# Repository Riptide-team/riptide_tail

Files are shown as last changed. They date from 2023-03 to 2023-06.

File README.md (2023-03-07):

# Compilation

## Arduino makefile

To compile and upload the code on the Arduino, [Arduino-Makefile](https://github.com/sudar/Arduino-Makefile) is used. Once installed, go to src, check that the arduino port is the port put in the Makefile at `MONITOR_PORT  = /dev/ttyUSB0`, and execute `make upload` 

# Serial communication

## Baudrate

The baudrate is `115200` and the communication is operating over usb between arduino and Raspberry Pi.

## Commands from raspberry

### Command frame
Commands from raspberry are sent using bytes. The line is finished by a `LF` (`\n`).

### Frame content
Bytes are hex values between 1000 and 2000 (coded on two consecutive bytes) which are direct us request on the output channel.
Channel order is :

- Thruster channel
- D fin channel
- P fin channel
- S fin channel

### Example

All to neutral:

`\0x05\0xDC\0x05\0xDC\0x05\0xDC\0x05\0xDC\0x0A`

Thruster full forward, fins full backward:

`\0x07\0xD0\0x03\0xE8\0x03\0xE8\0x53\0xE8\0x0A`

## Commands from arduino

### Command frame
Commands from raspberry are sent using bytes. The line is finished by a `LF` (`\n`).

### Frame content
Bytes are hex values between 1000 and 2000 (on three hexadecimal digits) which are direct us request from the RC captured by arduino and real generated PWM to actuators.
Channel order is :

- Thruster channel
- D fin channel
- P fin channel
- S fin channel
- RC channel 1 (Manual button)
- RC channel 2 (Timer button)
- RC channel 3 (Thruster)
- RC channel 4 (D fin)
- RC channel 5 (P fin)
- RC channel 6 (S fin)

### Example

All to neutral:

`\0x05\0xDC\0x05\0xDC\0x05\0xDC\0x05\0xDC\0x05\0xDC\0x05\0xDC\0x05\0xDC\0x05\0xDC\0x05\0xDC\0x05\0xDC\0x0A`

Thruster full forward, fins full backward, in manual mode, with timer at the minimum, so the RC captured commands are commands applied to the actuators:

`\0x07\0xD0\0x03\0xE8\0x03\0xE8\0x53\0xE8\0x07\0xD0\0x03\0xE8\0x07\0xD0\0x03\0xE8\0x03\0xE8\0x53\0xE8\0x0A`

## Picocom serial debug

To debug the serial communication, picocom can be used with the following configuration to correctly print hex characters:

```bash
picocom --imap spchex,nrmhex,8bithex,lfcrlf /dev/ttyUSB0 -b 115200
```

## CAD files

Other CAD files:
cad/parts/riptide_servomotors_bracket.FCStd
cad/parts/riptide_tail_top.FCStd
cad/parts/riptide_tail_bottom.FCStd

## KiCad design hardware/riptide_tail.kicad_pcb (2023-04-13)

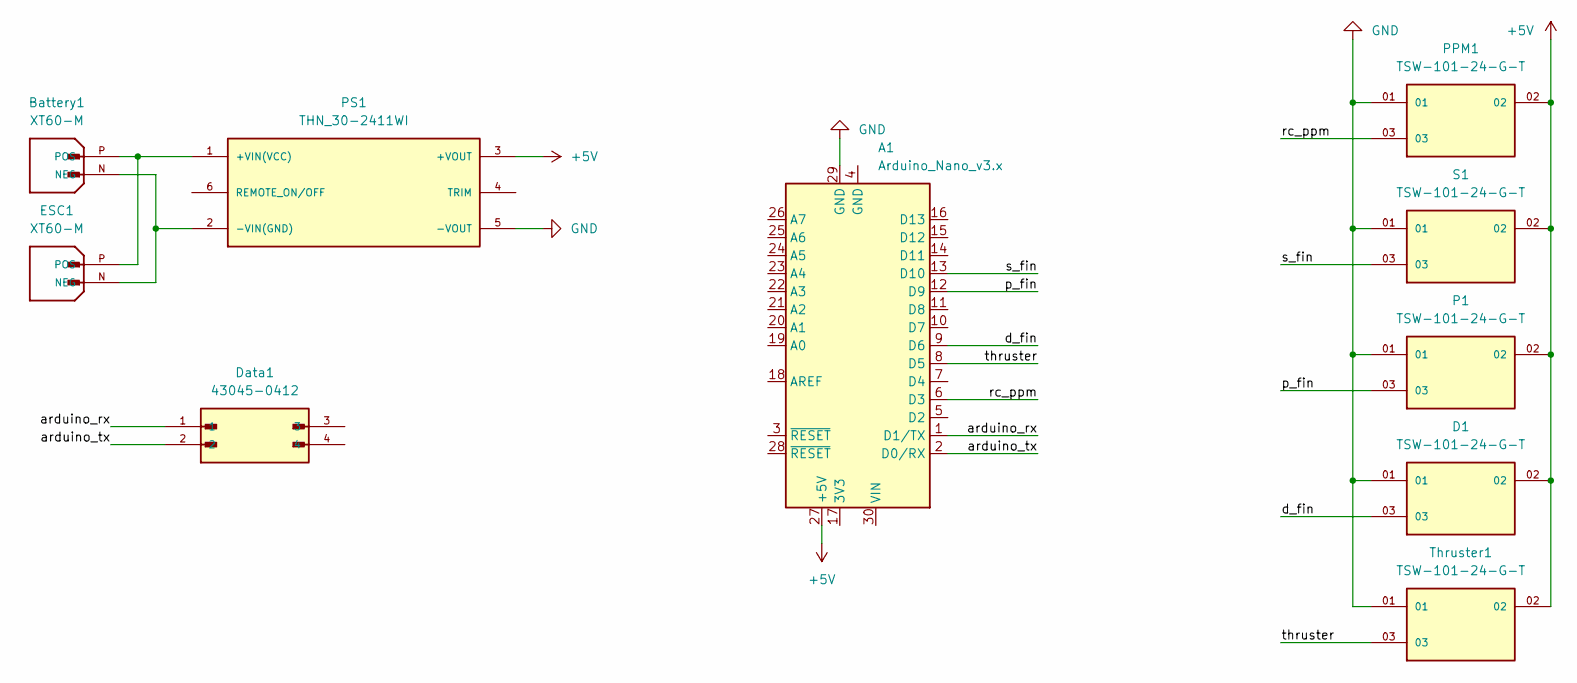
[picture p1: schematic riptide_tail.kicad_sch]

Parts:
A1: Arduino_Nano_v3.x; Arduino_Nano
Battery1: XT60-M; AMASS_XT60-M; PARTREV V1.2
D1: TSW-101-24-G-T; SAMTEC_TSW-101-24-G-T; PARTREV R
Data1: 43045-0412; MOLEX_43045-0412; PARTREV G1
ESC1: XT60-M; AMASS_XT60-M; PARTREV V1.2
P1: TSW-101-24-G-T; SAMTEC_TSW-101-24-G-T; PARTREV R
PPM1: TSW-101-24-G-T; SAMTEC_TSW-101-24-G-T; PARTREV R
PS1: THN_30-2411WI; CONV_THN_30-2411WI; PARTREV March 16, 2021
S1: TSW-101-24-G-T; SAMTEC_TSW-101-24-G-T; PARTREV R
Thruster1: TSW-101-24-G-T; SAMTEC_TSW-101-24-G-T; PARTREV R

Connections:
+5V: A1.27 (+5V), D1.02, P1.02, PPM1.02, PS1.3 (+VOUT), S1.02, Thruster1.02
/arduino_rx: A1.1 (D1/TX), Data1.1
/arduino_tx: A1.2 (D0/RX), Data1.2
/d_fin: A1.9 (D6), D1.03
/p_fin: A1.12 (D9), P1.03
/rc_ppm: A1.6 (D3), PPM1.03
/s_fin: A1.13 (D10), S1.03
/thruster: A1.8 (D5), Thruster1.03
GND: A1.29 (GND), D1.01, P1.01, PPM1.01, PS1.5 (-VOUT), S1.01, Thruster1.01
unnamed: Battery1.N (NEG), ESC1.N (NEG), PS1.2 (-VIN(GND))
unnamed: Battery1.P (POS), ESC1.P (POS), PS1.1 (+VIN(VCC))

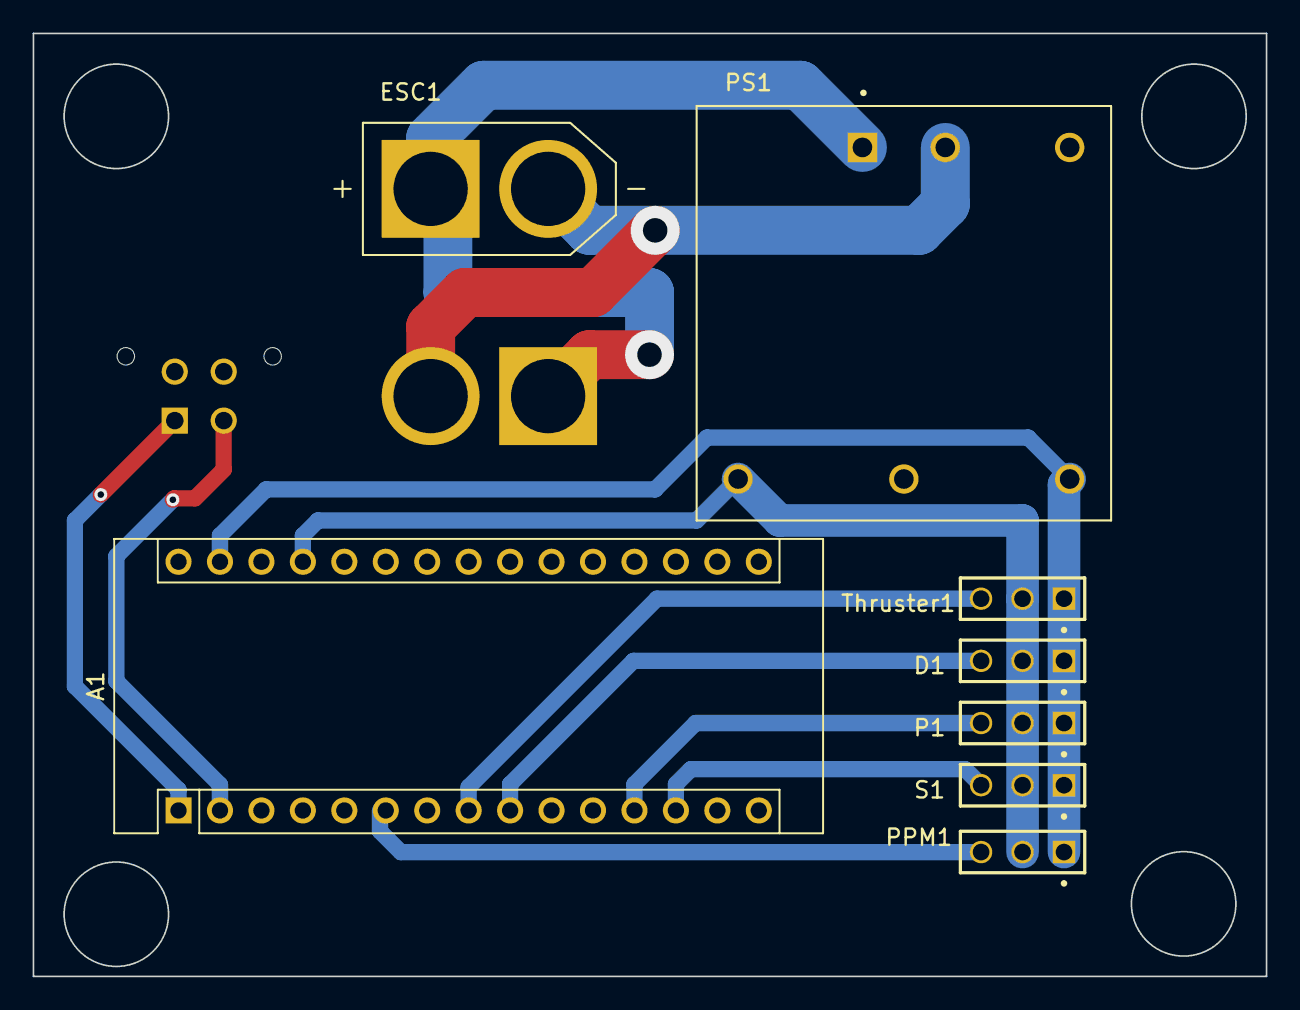
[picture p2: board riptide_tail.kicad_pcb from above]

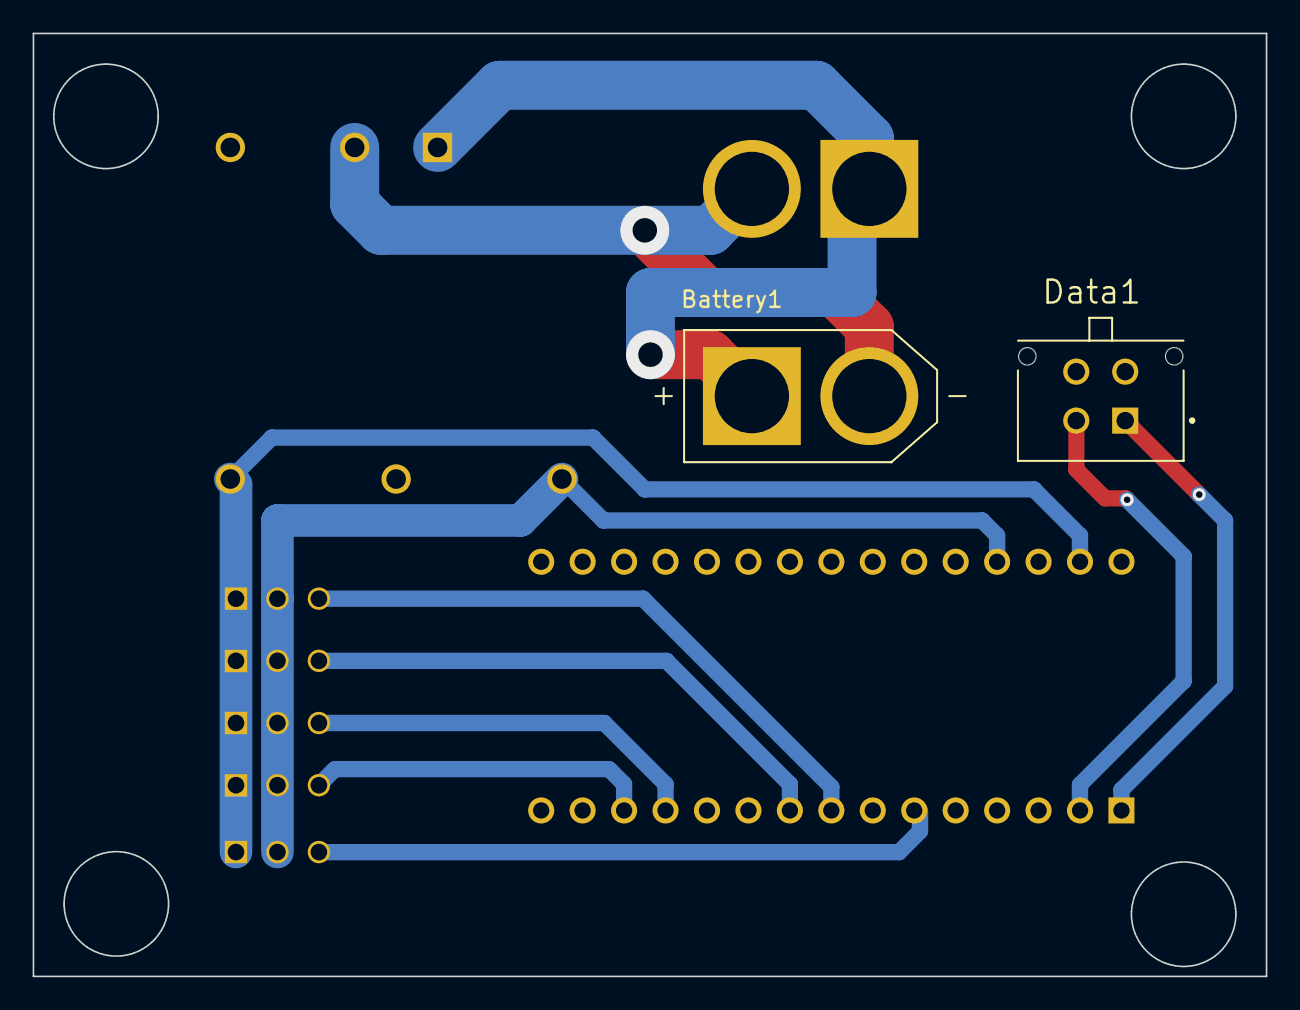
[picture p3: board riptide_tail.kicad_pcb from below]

Board: 2 copper layers, 75.6 x 57.8 mm, 10 parts (2 on the bottom side), 11 nets.

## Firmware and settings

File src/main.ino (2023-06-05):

#include <NMEAParser.h>
#include <PPMReader.h>
#include <Servo.h>
#include <string.h>


// Loop delay
#define LOOP_DELAY 40      // ms
uint32_t t0_loop_time;

// Initialize a PPMReader on digital pin 3 with 6 expected channels.
#define RC_PIN 3            // D3
#define CHANNEL_AMOUNT 6    // number of PPM channel
PPMReader ppm(RC_PIN, CHANNEL_AMOUNT);

// Initialize actuators outputs
#define THRUSTER_PIN 5      // D5
#define D_FIN_PIN 6         // D6
#define P_FIN_PIN 9         // D9
#define S_FIN_PIN 10        // D10

Servo thruster;
Servo d_fin;
Servo p_fin;
Servo s_fin;

// PWM Neutral in us
#define PWM_NEUTRAL 1500

// Manual mode threshold
#define MANUAL_THRESHOLD 1750
bool manual=false;

// Multiplexer RC Timer button pressed
bool rc_timer_button_pressed=false;

// Previous time_value
uint16_t previous_time_value;

// NMEA Parser declared with 1 handler for RHACT sentences
NMEAParser<1> parser;

// Read serial buffer
uint16_t read_serial_buffer[4];

// Read stopping criterion to not block the loop
bool complete_frame = false;
uint8_t read_cursor = 0;
uint8_t read_cursor_max = 128;

// Last time command received from serial
#define SERIAL_TIMEOUT 3000
uint32_t time_read_serial = 0;

// RC read buffer
uint16_t read_rc_buffer[CHANNEL_AMOUNT];

// Initialize serial write buffers
uint16_t write_buffer[4];

// Maximum time for multiplexer in ms (compared to millis() to know how to multiplex RC and Raspberry Pi)
unsigned long t_multiplexer_max;

bool valid_commands(uint16_t *buffer) {
    if (
        (1000 <= buffer[0]) and (buffer[0] <= 2000) and
        (1000 <= buffer[1]) and (buffer[1] <= 2000) and
        (1000 <= buffer[2]) and (buffer[2] <= 2000) and
        (1000 <= buffer[3]) and (buffer[3] <= 2000)
    ) {
        return true;
    }
    else {
        return false;
    }
}

void write_actuators() {
    thruster.writeMicroseconds(write_buffer[0]);
    d_fin.writeMicroseconds(write_buffer[1]);
    p_fin.writeMicroseconds(write_buffer[2]);
    s_fin.writeMicroseconds(write_buffer[3]);
}

void RHACT_handler() {
    // Set complete_frame to true to perform a write after the parsing of this NMEA sentence
    complete_frame = true;

    // If the number of arguments is correct
    if (parser.argCount() == 4) {

        // Try reading each arguments
        bool read_flag = true;
        uint16_t temporary_read_buffer[4];

        for (uint8_t i = 0; i<4; ++i) {
            int value;
            read_flag &= parser.getArg(i, value);
            temporary_read_buffer[i] = value;
        }

        // If there is no errors, copying it in read_buffer
        if (read_flag) {
            memcpy(read_serial_buffer, temporary_read_buffer, 4*sizeof(uint16_t));
        }
        time_read_serial = millis();
    }
}

uint8_t CRC(char* buffer, uint8_t n) {
    uint8_t crc = 0;
    for (uint8_t i = 0; i < n; ++i){ // XOR every character
      crc = crc ^ buffer[i] ;  // compute CRC
    }
    return crc;
}

void CheckSum(uint8_t &checksum, char c) {
    checksum = checksum ^ c;  // compute CRC
}

char toUpper(char c) {
    if(c >= 'a' && c <= 'z') c += 'A' - 'a';
    return c;
}


void RTRCR_write() {
    // Header
    uint8_t checksum = 105; 
    Serial.print("$RTRCR,");

    for (uint8_t channel = 0; channel < CHANNEL_AMOUNT; ++channel) {
        // Printing Channel
        Serial.print(read_rc_buffer[channel]);

        // Computing CheckSum
        char channel_buffer[4];
        itoa(read_rc_buffer[channel], channel_buffer, 10);
        for (uint8_t i=0; i<4; ++i) {
            CheckSum(checksum, channel_buffer[i]);
        }

        // Adding ',' except for the last loop 
        if (channel < CHANNEL_AMOUNT-1) {
            Serial.print(',');
            CheckSum(checksum, ',');
        }
    }

    // Printing *
    Serial.print("*");

    // Printing CRC and ending the frame
    char crc_buffer[3];
    itoa (checksum, crc_buffer, 16);
    Serial.print(toUpper(crc_buffer[0]));
    Serial.print(toUpper(crc_buffer[1]));

    // Printing \r\n
    Serial.print("\r\n");
}

void RTACT_write() {
    // Header
    uint8_t checksum = 124; 
    Serial.print("$RTACT,");

    // Building NMEA sentence
    for (uint8_t channel = 0; channel < 4; ++channel) {
        // Printing channel value
        Serial.print(write_buffer[channel]);

        // Computing checksum
        char channel_buffer[4];
        itoa(write_buffer[channel], channel_buffer, 10);
        for (uint8_t i=0; i<4; ++i) {
            CheckSum(checksum, channel_buffer[i]);
        }

        // Adding ',' except for the last loop 
        if (channel < 3) {
            Serial.print(',');
            CheckSum(checksum, ',');
        }
    }

    // Printing *
    Serial.print("*");

    // Printing CRC and ending the frame
    char crc_buffer[3];
    itoa (checksum, crc_buffer, 16);
    Serial.print(toUpper(crc_buffer[0]));
    Serial.print(toUpper(crc_buffer[1]));

    // Printing \r\n
    Serial.print("\r\n");
}

void RTMPX_write() {
    // Header
    uint8_t checksum = 111; 
    Serial.print("$RTMPX,");

    // Computing remaining time
    float remaining_time = ((float)t_multiplexer_max - (float)millis()) / 1000.f;

    // Printing first argument (0 for RC / 1 for RH)
    if ((manual) or (remaining_time < 0.f)) {
        Serial.print('0');
        CheckSum(checksum, '0');
    }
    else {
        Serial.print('1');
        CheckSum(checksum, '1');
    }
    
    // Printing ','
    Serial.print(',');
    CheckSum(checksum, ',');

    // Printing remaining seconds
    if (remaining_time >= 0.f) {
        // Computing seconds, dsecs, csecs and msecs
        int secs = int(remaining_time);
        int msecs = int(remaining_time*1000 - secs*1000);

        // Putting int part
        uint8_t i = 0;
        char time_buffer[3];
        itoa(secs, time_buffer, 10);
        while ((i<3) and (time_buffer[i] != '\0')) {
            Serial.print(time_buffer[i]);
            CheckSum(checksum, time_buffer[i]);
            i++;
        }

        Serial.print('.');
        CheckSum(checksum, '.');

        // Putting int part
        i = 0;
        itoa(msecs, time_buffer, 10);
        while ((i<3) and (time_buffer[i] != '\0')) {
            Serial.print(time_buffer[i]);
            CheckSum(checksum, time_buffer[i]);
            i++;
        }
    }
    else {
        Serial.print("0.000");
        CheckSum(checksum, '0');
        CheckSum(checksum, '.');
        CheckSum(checksum, '0');
        CheckSum(checksum, '0');
        CheckSum(checksum, '0');
    }

    // Printing *
    Serial.print("*");

    // Printing CRC and ending the frame
    char crc_buffer[3];
    itoa(checksum, crc_buffer, 16);
    Serial.print(toUpper(crc_buffer[0]));
    Serial.print(toUpper(crc_buffer[1]));

    // Printing \r\n
    Serial.print("\r\n");
}


void setup() {
    // Serial communication with raspberry
    Serial.begin(115200);

    // Add handler to the parser
    parser.addHandler("RHACT", RHACT_handler);

    // Servo creation
    thruster.attach(THRUSTER_PIN);
    d_fin.attach(D_FIN_PIN);
    p_fin.attach(P_FIN_PIN);
    s_fin.attach(S_FIN_PIN);

    // PPM tuning
    ppm.minChannelValue = 1000;     // (us)
    ppm.maxChannelValue = 2000;     // (us)
    ppm.channelValueMaxError = 40;  // (us)
    ppm.blankTime = 2500;           // (us)

    // Filling read buffers to neutral commands
    for (uint8_t i=0; i<4; ++i) {
        read_serial_buffer[i] = PWM_NEUTRAL;
    }
    for (uint8_t i=0; i<CHANNEL_AMOUNT; ++i) {
        read_rc_buffer[i] = PWM_NEUTRAL;
    }

    // Init t0
    t_multiplexer_max = millis();

    // read_serial and write_buffer init
    for (uint8_t i = 0; i < 4; ++i) {
        write_buffer[i] = PWM_NEUTRAL;
        read_serial_buffer[i] = PWM_NEUTRAL;
    }
}

void loop() {
    // Getting t0_loop time
    t0_loop_time = millis();

    // Reading PPM RC Receiver into write buffer
    for (uint8_t channel = 0; channel < CHANNEL_AMOUNT; ++channel) {
        read_rc_buffer[channel] = ppm.latestValidChannelValue(channel, PWM_NEUTRAL);
    }

    // Write RTRCR NMEA sentences
    RTRCR_write();

    // Reading commands from serial
    while ((read_cursor < read_cursor_max) and (!complete_frame) and (Serial.available())) {
        // Reading incomming char into the NMEA parser
        parser << Serial.read();
        read_cursor++;
    }

    // Reseting the complete frame variable to parse sentences
    complete_frame = false;
    read_cursor = 0;

    // Checking if the manual button is triggered
    uint16_t manual_value = read_rc_buffer[0];
    if (manual_value > MANUAL_THRESHOLD) {
        manual = true;
    }
    else {
        manual = false;
    }

    // Getting the current time
    unsigned long current_time = millis();

    // Getting time from RC if provided
    uint16_t time_value = read_rc_buffer[1];
    if (time_value > PWM_NEUTRAL) {
        rc_timer_button_pressed = true;
    }
    else {
        // If the button was previously pressed
        if (rc_timer_button_pressed) {
            // Setting end mission time in ms
            t_multiplexer_max = ((unsigned long)current_time + 200ul * (max(0, (uint32_t)previous_time_value - 1500)));
            rc_timer_button_pressed = false;
        }
    }
    previous_time_value = time_value;

    // Writing commands on actuators depending on the manual or automatic mode and remaining multiplexer time
    if (manual) {
        memcpy(write_buffer, read_rc_buffer+2, 4*sizeof(uint16_t));
    }
    else {
        // If the current time is over the multiplexer time or the last time a command was received is greater than SERIAL_TIMEOUT
        if ((current_time - time_read_serial > SERIAL_TIMEOUT) or (current_time > t_multiplexer_max) or (!valid_commands(read_serial_buffer))) {
            // Setting all servos to neutral
            for (uint8_t i=0; i<4; ++i) {
                write_buffer[i] = PWM_NEUTRAL;
            }
        }
        else {
            // Write serial received commands to actuators
            memcpy(write_buffer, read_serial_buffer, 4*sizeof(uint16_t));
        }
    }

    write_actuators();

    // Write RTACT NMEA sentences
    RTACT_write();

    // Write RTMPX NMEA sentences
    RTMPX_write();

    // Loop delay
    delay(LOOP_DELAY);
}

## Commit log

2023-04-11 Adding cad
    [riptide_tail_bottom.FCStd, riptide_tail_top.FCStd]
2023-04-13 Updating CAO&EDA
    [riptide_servomotors_bracket.FCStd, riptide_tail.kicad_pcb, riptide_tail.kicad_sch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]
2023-04-13 Adding pvc color
    [riptide_servomotors_bracket.FCStd, riptide_tail_bottom.FCStd, riptide_tail_top.FCStd]
2023-06-05 Updating arduino script
